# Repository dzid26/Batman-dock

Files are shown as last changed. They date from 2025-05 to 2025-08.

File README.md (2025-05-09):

- KiCad 9
    - [Fabrication plugin](https://github.com/bennymeg/Fabrication-Toolkit)
- FreeCAD 1.1
    - Use [exportProject.FCMacro](https://gist.github.com/dzid26/e0ff365de43cabe658df9d93b92d1954) to quickly export step files with a macro
    - KiStepUp plugin to export `PCB_Sketch_master.stp` to Kicad and import part positions from Kicad



The design accounts for windshield curvature (R=4m). Although in hindsight this is not very useful as it translates to only 0.08mm surface delta for the batman width. The 3d printer can do it, but bigger effects might be even due to part warping and flex.

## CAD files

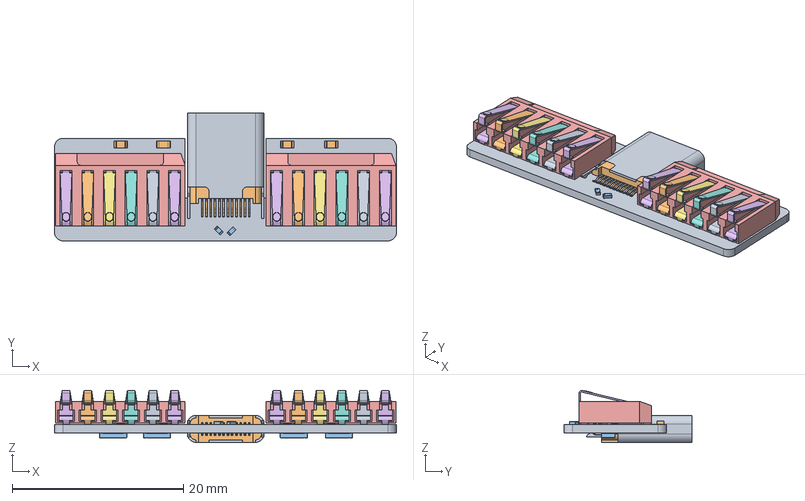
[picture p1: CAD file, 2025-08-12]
Batman-dock_KicadStepUP_import.FCStd
40.0 x 15.0 x 6.08 mm
Pcb_761f
R2_R_0603_1608Metric_0c4d062e0f3a x 4
R5_R_0402_1005Metric_9ec334378073 x 2
70AAJ-6-M0 x 2
70AAJ-6-M001 x 2
70AAJ-6-M002 x 2
70AAJ-6-M003 x 2
70AAJ-6-M004 x 2
70AAJ-6-M005 x 2
70AAJ-6-M006 x 2
70AAJ-6-M007 x 2
70AAJ-6-M008 x 2
70AAJ-6-M009 x 2
70AAJ-6-M010 x 2
70AAJ-6-M011 x 2
70AAJ-6-M012 x 2
USB-SMD_HC-TYPE-C-24P-CP1.0-5A-L10.45-01
USB-SMD_HC-TYPE-C-24P-CP1.0-5A-L10.45-002
CAN0_R_1206_3216Metric_c237a550c969 x 4

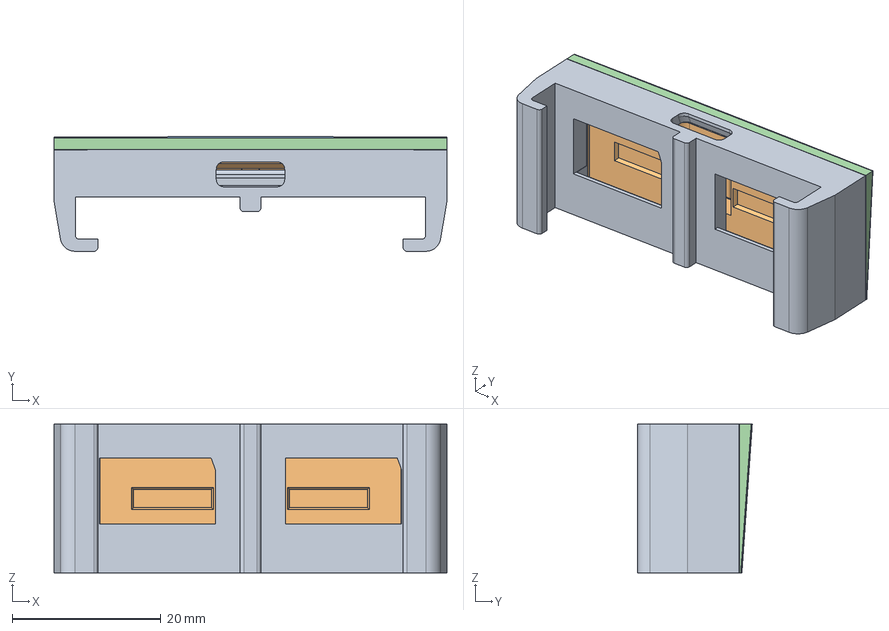
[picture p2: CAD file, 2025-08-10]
Batman-dock.FCStd
52.8 x 15.4 x 20.0 mm
Main[step]
Backplate[step]
Batman spacer 4deg [step]
Batman spacer flat 4deg [step]

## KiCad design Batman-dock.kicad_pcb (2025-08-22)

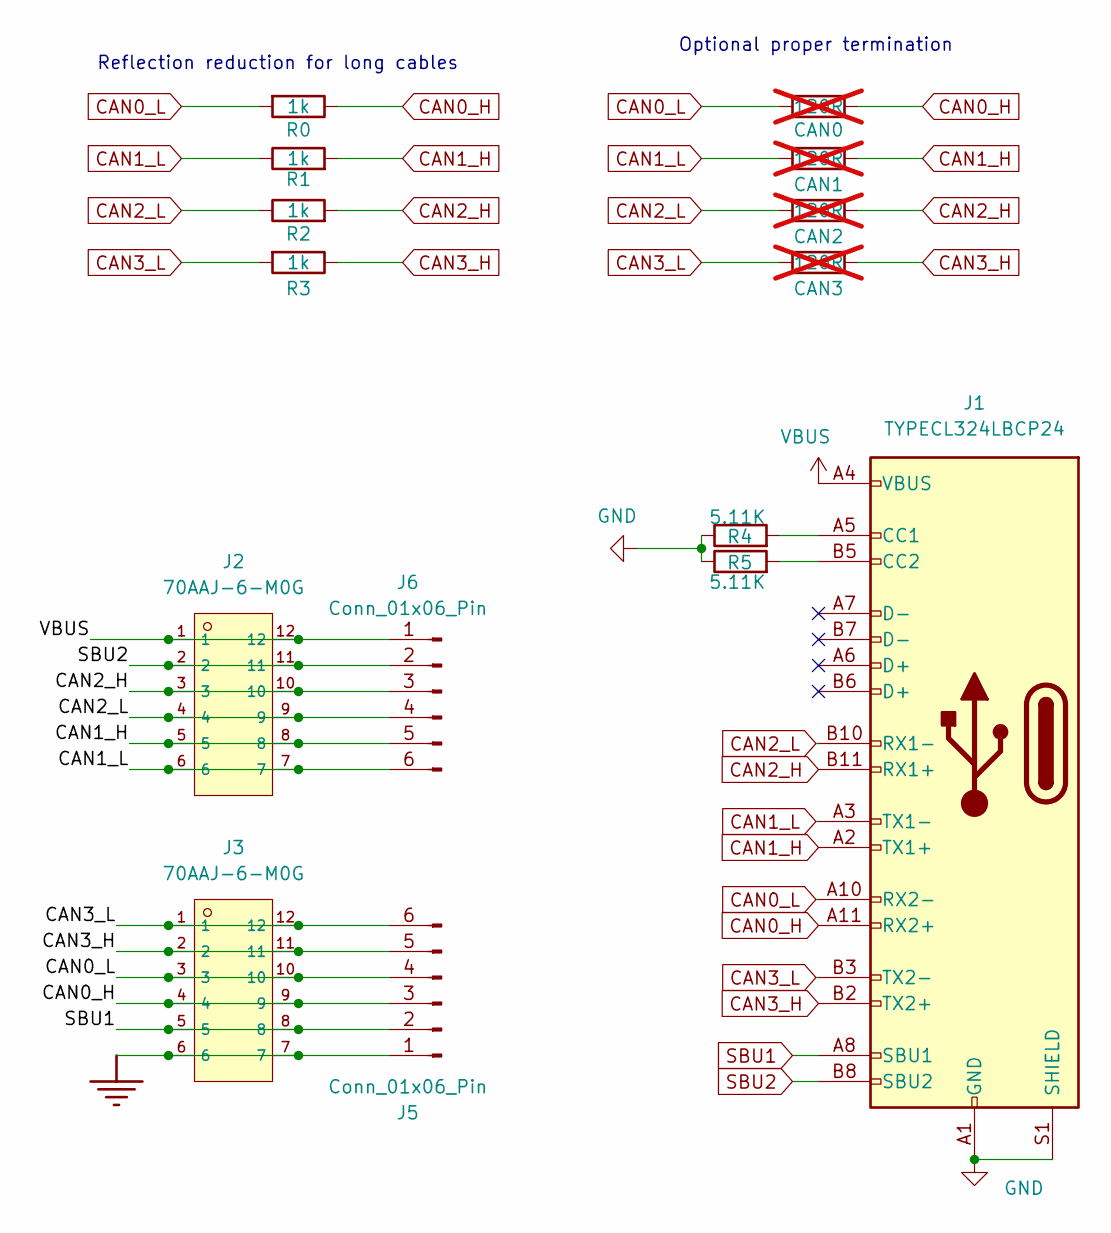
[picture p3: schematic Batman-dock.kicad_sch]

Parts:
CAN0, CAN1, CAN2, CAN3: 120R; R_1206_3216Metric_Pad1.30x1.75mm_HandSolder; not fitted
J1: TYPECL324LBCP24; USB-SMD_HC-TYPE-C-24P-CP1.0-5A-L10.45-01; LCSC C5345938
J2, J3: 70AAJ-6-M0G; CONN-SMD_12P-P2.54_70AAJ-6-M0G; LCSC C5137163
J5, J6: Conn_01x06_Pin; PinHeader_1x06_P2.54mm_Vertical
R0, R1, R2, R3: 1k; R_0603_1608Metric
R4, R5: 5.11K; R_0402_1005Metric; LCSC Part # C25905

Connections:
CAN0_H: CAN0.1, J1.A11 (RX2+), J3.4, J3.9, J5.3, R0.1
CAN0_L: CAN0.2, J1.A10 (RX2-), J3.3, J3.10, J5.4, R0.2
CAN1_H: CAN1.1, J1.A2 (TX1+), J2.5, J2.8, J6.5, R1.2
CAN1_L: CAN1.2, J1.A3 (TX1-), J2.6, J2.7, J6.6, R1.1
CAN2_H: CAN2.1, J1.B11 (RX1+), J2.3, J2.10, J6.3, R2.2
CAN2_L: CAN2.2, J1.B10 (RX1-), J2.4, J2.9, J6.4, R2.1
CAN3_H: CAN3.1, J1.B2 (TX2+), J3.2, J3.11, J5.5, R3.1
CAN3_L: CAN3.2, J1.B3 (TX2-), J3.1, J3.12, J5.6, R3.2
GND: J1.A1 (GND), J1.A12 (GND), J1.B1 (GND), J1.B12 (GND), J1.S1 (SHIELD), J3.6, J3.7, J5.1, R4.1, R5.1
unnamed: J1.A5 (CC1), R4.2
unnamed: J1.B5 (CC2), R5.2
SBU1: J1.A8 (SBU1), J3.5, J3.8, J5.2
SBU2: J1.B8 (SBU2), J2.2, J2.11, J6.2
VBUS: J1.A4 (VBUS), J1.A9 (VBUS), J1.B4 (VBUS), J1.B9 (VBUS), J2.1, J2.12, J6.1

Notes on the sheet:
Optional proper termination
Reflection reduction for long cables

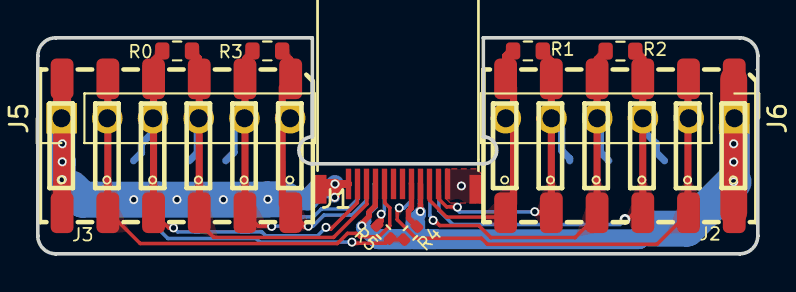
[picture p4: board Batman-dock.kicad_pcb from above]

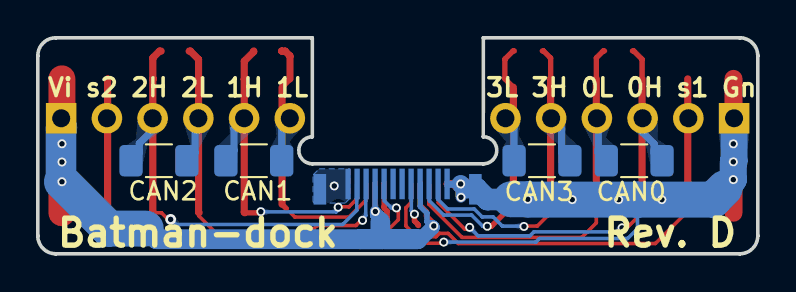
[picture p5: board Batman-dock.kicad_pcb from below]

Board: 2 copper layers, 40.0 x 12.0 mm, 15 parts (4 on the bottom side), 14 nets.

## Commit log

2025-03-03 Intitail Batman dock
    [Batman-dock.FCStd, Batman-dock.kicad_pcb, Batman-dock.kicad_sch]
2025-03-04 Kicad 9. Added usb and spring footprint.
    [Batman-dock.kicad_pcb, Batman-dock.kicad_sch]
2025-03-07 Batman routing
    [Batman-dock.FCStd, Batman-dock.kicad_pcb, Batman-dock.kicad_sch]
2025-03-07 batman more clearance
    [Batman-dock.kicad_pcb]
2025-03-08 1mm batman PCB
    [Batman-dock.FCStd, Batman-dock.kicad_pcb, Batman-dock.kicad_sch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]
2025-03-11 Batman sliding backplate
    [Batman-dock.FCStd, Batman-dock_KicadStepUP_import.FCStd]
2025-03-13 20mm wide
    [Batman-dock.FCStd]
2025-03-14 backplate tolerance and interlock
    [Batman-dock.FCStd]
2025-03-15 back insert slot and refinments
    [Batman-dock.FCStd]
2025-03-15 USB-C backplate cutout
    [Batman-dock.FCStd]
2025-03-17 refined design, insert interlock front/back, added crappy 8deg
    [Batman-dock.FCStd]
2025-03-17 interlock masking
    [Batman-dock.FCStd]
2025-03-17 end slot tolerance
    [Batman-dock.FCStd]
2025-03-17 enlarged usb-c cutout
    [Batman-dock.FCStd]
2025-03-17 rounded facade
    [Batman-dock.FCStd]
2025-03-21 Added simple and simple 8deg batmans
    [Batman-dock.FCStd]
2025-03-23 Added windshield curvature (miniscule), interlock geometry optimizations
    [Batman-dock.FCStd]
2025-04-21 Added 3deg version. Optimized USB-C hole, and bridge for printing.
    [Batman-dock.FCStd]
2025-04-21 Make space for 0402 resistors. 3deg to 4deg.
    [Batman-dock.FCStd]
2025-04-21 Fixed CAN order RX<->TX flip. Less copper.
    [Batman-dock.kicad_pcb, Batman-dock.kicad_sch, Batman-dock_KicadStepUP_import.FCStd]
2025-04-21 Shorter PCB: 42mm -> 40mm
    [Batman-dock.FCStd, Batman-dock.kicad_pcb, Batman-dock_KicadStepUP_import.FCStd]
2025-04-23 Backplate push on PCB. Backplate insertion tolerance.
    [Batman-dock.FCStd, Batman-dock.kicad_pcb]
2025-04-26 thicker ground
    [Batman-dock.kicad_pcb]
2025-04-26 Flipped USB so it's "placed on top"
    [Batman-dock.kicad_pcb]
2025-05-07 more tolerance for interlocks - easier insertion
    [Batman-dock.FCStd]
2025-05-09 Added simple 4deg batman Good for BMW E series with more "vertical" windshield
    [Batman-dock.FCStd]
2025-06-22 Fixed 70AAJ-6-M0G name
    [Batman-dock.kicad_pcb, Batman-dock.kicad_sch]
2025-07-05 Rev.D added anti-reflection resistors and termination footprints. Added through hole test points
    [Batman-dock.FCStd, Batman-dock.kicad_pcb, Batman-dock.kicad_sch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]
2025-08-10 -4deg batman and 4deg spacers
    [Batman-dock.FCStd]
2025-08-12 Disable document compression
    [Batman-dock_KicadStepUP_import.FCStd]
2025-08-22 PCB remarks and DNP
    [Batman-dock.kicad_pcb, Batman-dock.kicad_sch]
